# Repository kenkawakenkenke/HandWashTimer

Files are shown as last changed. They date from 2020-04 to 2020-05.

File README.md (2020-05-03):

# 石鹸を出すと30秒音のなるハンドソープ台

## 概要

ハンドソープをプッシュすると、30秒間の曲が鳴る台です。我が家では、これを導入してから[子供がきっちり30秒間丁寧に手を洗うようになってくれました](https://twitter.com/kenkawakenkenke/status/1246731640165957638)。

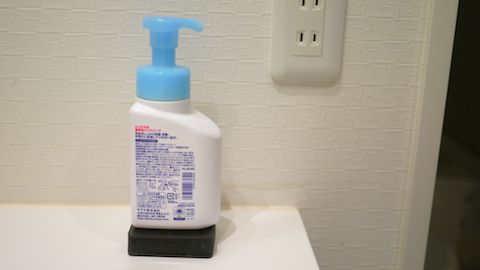
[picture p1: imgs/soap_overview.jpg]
完成図


## 必要なもの

### 工作キットを購入した場合

[工作キット](https://kenkawakenkenke.stores.jp/items/5eab6c5472b9115e7e576797)を購入いただいた場合、他に必要なものは：

 * [はんだごて](https://www.amazon.co.jp/s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)
 * [はんだ](https://www.amazon.co.jp/s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)
 
だけです。
 
### 自分で部品を用意する場合

上記に加え、以下の部品を用意しましょう：

 * [ATTiny85](http://akizukidenshi.com/catalog/g/gI-09573/)：[HandWashTimer85のプログラム](Arduino/HandWashTimer85.ino)を書き込んでください。
 * [ユニバーサル基板](http://akizukidenshi.com/catalog/g/gP-11735/)：なんでもいいですが、ピン数が16x16以上必要です。
 * [圧電スピーカー](http://akizukidenshi.com/catalog/g/gP-04119/)
 * [CR2032電池ホルダー](http://akizukidenshi.com/catalog/g/gP-00706/)
 * [CR2032電池](http://akizukidenshi.com/catalog/g/gB-05694/)
 * [タクトスイッチ](http://akizukidenshi.com/catalog/g/gP-09623/)：他の部品よりも背が高いものを選んでください
 * ケース：基板を設置し、ハンドソープを乗せるためのケースを用意しましょう。[工作キット](https://kenkawakenkenke.stores.jp/items/5eab6c5472b9115e7e576797)にはちょうどよいアクリルケースが付属しています。

### 基板を組み立てる

以下の回路図を参考に、基板を組立ててください：

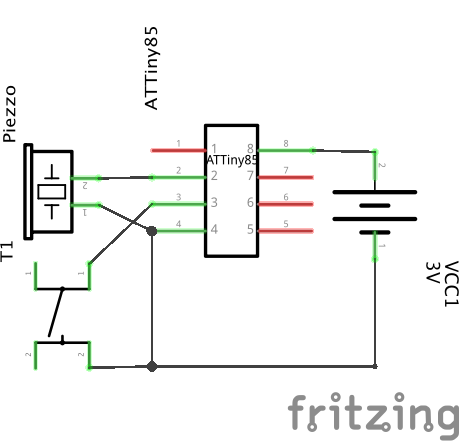
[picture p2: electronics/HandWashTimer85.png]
回路図


 * マイコンと電池は熱に弱いため、はんだ付け時はソケットから抜いておきましょう。
 * 部品には向きがあります。下記写真を参考にしてください。

参考までに、部品はこんな感じで置くときれいに収まります。特に、トグルスイッチをなるべく真ん中に置くと、ソープを押したときの安定性が増します。

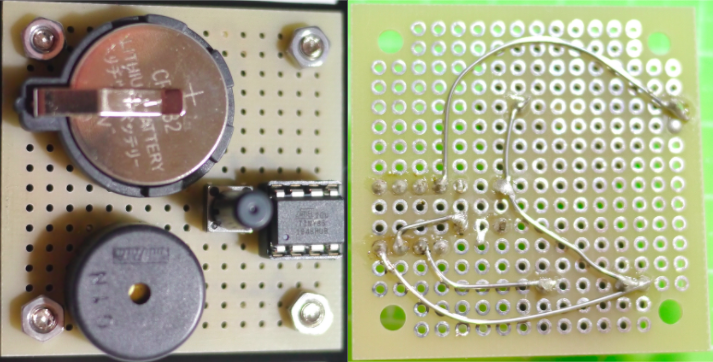
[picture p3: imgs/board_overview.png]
回路組み立てイメージ


添付のスズメッキ線を使って丁寧に配線してください。

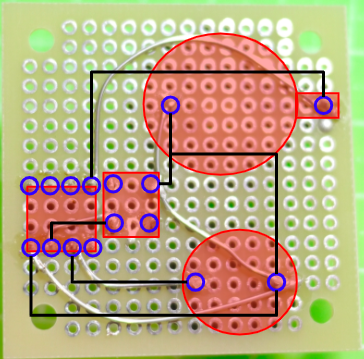
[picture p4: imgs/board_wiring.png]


電池とマイコンをセットして、タクトスイッチを押したら30秒間曲がなるはずです。

### 本体の組み立て
まずは底面アクリル（穴が空いたほう）に基板をネジ止めしましょう。

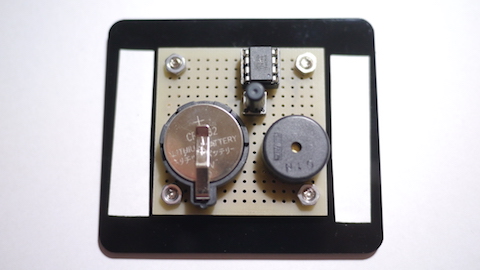
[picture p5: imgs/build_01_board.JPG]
組み立て：ネジ止め


次に、必要に応じてトグルスイッチの高さを調整します。出荷直後の状態だと、トグルスイッチの背が高すぎて本体の安定性が悪い場合があります。そのため、他の部品よりも数mmだけ高いように、スイッチ上部を切断しましょう：

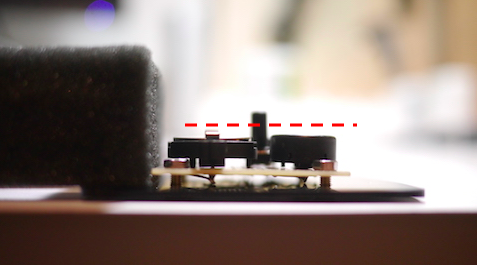
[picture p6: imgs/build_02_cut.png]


アクリルについている両面テープの保護材を剥がして、付属のスポンジをくっつけましょう。

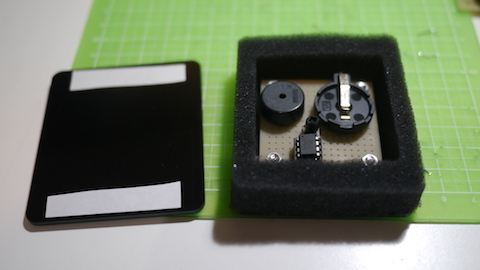
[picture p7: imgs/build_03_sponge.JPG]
スポンジ設置


上面のアクリルを同じようにくっつけて、完成です。

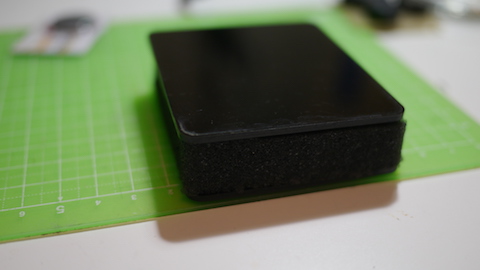
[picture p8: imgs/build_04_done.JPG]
上面アクリル設置


ハンドソープを上において、プッシュしたら曲がなることを確認しましょう。

## 好きな音楽をプログラミングする
TODO(ken): 書く

キットに付属しているマイコン（ATTiny85）は、すでに30秒間の威風堂々が鳴るようにプログラムされています。これをご自身の書いたプログラムで置き換えることで、好きな曲に変えたり、別の挙動をさせたりすることができます。

1. [こういうガイド](https://miraluna.hatenablog.com/entry/tiny85)を見ながら、ATTiny85にArduinoのスケッチを書き込める環境を整えましょう。

2. 本プロジェクトの[デフォルトのプログラム]((Arduino/HandWashTimer85.ino))をダウンロードして、好きに改変してみましょう。

3. 面白いのができたらSNSに投稿しましょう。

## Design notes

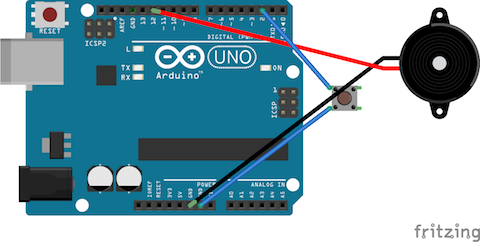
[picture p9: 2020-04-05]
electronics/HandWashTimer_bb.png

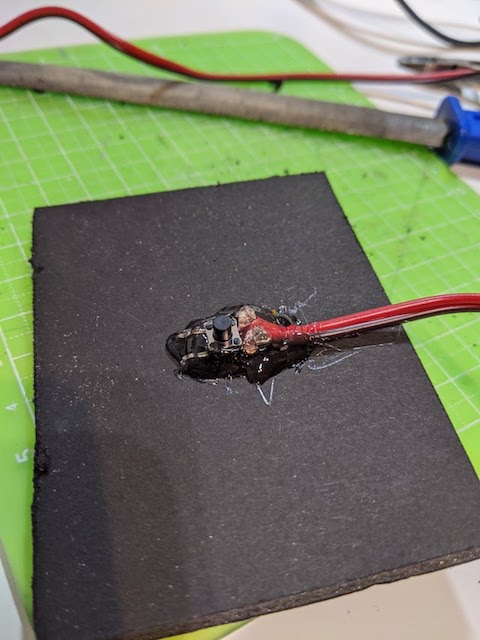
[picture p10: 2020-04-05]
imgs/tact_switch_480.jpg

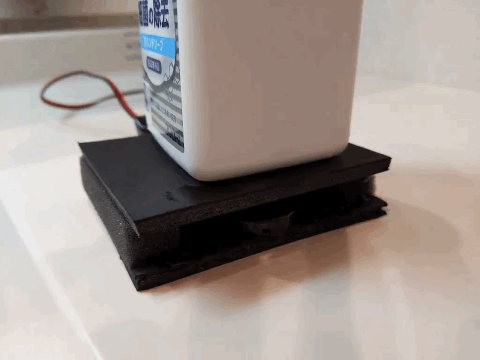
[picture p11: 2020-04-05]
imgs/timer_press.gif

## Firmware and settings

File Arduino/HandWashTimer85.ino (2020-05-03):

#include <avr/sleep.h>
#include <avr/power.h>

//                       +-\/-+
//      Ain0 (D 5) PB5  1|    |8  Vcc
// Tone Ain3 (D 3) PB3  2|    |7  PB2 (D 2) Ain1
// Itrp Ain2 (D 4) PB4  3|    |6  PB1 (D 1) pwm1
//                 GND  4|    |5  PB0 (D 0) pwm0
//                       +----+
#define PIN_WAKE 4
#define PIN_TONE 3

// Duration of a single unit tone.
// This was chosen so that "Pomp and Circumstances" runs for roughly 30 seconds.
#define TONE_UNIT_MS 312

#define B3  246
#define C4  261
#define D4  293
#define E4  329
#define F4  349
#define F4S 370
#define G4  392
#define A4  440
#define B4  493.88
#define C5  523.25
#define D5  587.33
#define E5  659
#define F5  698
#define G5  783
#define A5  880
#define B5  987


ISR (PCINT0_vect)
{
// do something interesting here
}

void setup() {
 pinMode (PIN_TONE, OUTPUT);
 
//  set_sleep_mode(SLEEP_MODE_PWR_DOWN);
  pinMode(PIN_WAKE, INPUT_PULLUP);
// pinMode (PIN_WAKE, INPUT);
//  digitalWrite (PIN_WAKE, HIGH);  // internal pull-up

// https://forum.arduino.cc/index.php?topic=234010.0
  // pin change interrupt (example for D4)
  PCMSK  |= bit (PCINT4);  // want pin D4 / pin 3
  GIFR   |= bit (PCIF);    // clear any outstanding interrupts
  GIMSK  |= bit (PCIE);    // enable pin change interrupts
}

void loop() {
//  digitalWrite(PIN_TONE, HIGH);
//  delay(500);
//  digitalWrite(PIN_TONE, LOW);
//  delay(500);
  
  sleepAndWaitForInterrupt();
  playPompAndCircumstance();
//  play(C5, 5);
//  for(int i=0;i<10;i++) {
//  digitalWrite(PIN_TONE, HIGH);
//  delay(100);
//  digitalWrite(PIN_TONE, LOW);
//  delay(100);
//  }
}


void sleepAndWaitForInterrupt() {
//  attachInterrupt(0, wakeUp, FALLING);
//  sleep_mode();
//  detachInterrupt(0);

   set_sleep_mode(SLEEP_MODE_PWR_DOWN);
  ADCSRA = 0;            // turn off ADC
  power_all_disable ();  // power off ADC, Timer 0 and 1, serial interface
  sleep_enable();
  sleep_cpu();                             
  sleep_disable();   
  power_all_enable();    // power everything back on
}

void wakeUp() {
  // Nothing to do on wakeup.
}

/**
   Play a single tone at the given frequency and length (in tone units).
   The length is 
*/
void play(float freq, int len) {
  tone(PIN_TONE, freq, len * TONE_UNIT_MS);
  delay(len * TONE_UNIT_MS);
  noTone(PIN_TONE);
}

/**
   Play Pomp and Circumstance
*/
void playPompAndCircumstance() {
  play(C5, 4);
  play(B4, 1);
  play(C5, 1);
  play(D5, 2);
  play(A4, 4);
  play(G4, 4);

  play(F4, 4);
  play(E4, 1);
  play(F4, 1);
  play(G4, 2);
  play(D4, 8);

  play(E4, 4);
  play(F4S, 1);
  play(G4, 2);
  play(A4, 1);
  play(D5, 4);
  play(G4, 4);

  play(F5, 4);
  play(F5, 1);
  play(E5, 2);
  play(D5, 1);
  play(E5, 8);

  play(A4, 4);
  play(B4, 1);
  play(C5, 2);
  play(D5, 1);
  play(G4, 4);
  play(C5, 4);

  play(C4, 4);
  play(F4, 1);
  play(E4, 2);
  play(D4, 1);
  play(C4, 8);
}

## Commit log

2020-04-05 initial commit adding schematics + code
    [HandWashTimer.fzz]
2020-05-03 Adds readme for the ATTiny85 kit + code and schematics
    [HandWashTimer85.fzz]
